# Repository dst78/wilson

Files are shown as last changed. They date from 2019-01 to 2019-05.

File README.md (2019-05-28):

# Wilson :: Sample and Hold

# WARNING: This module is quite buggy in its current state. I advise against using it for now.

This is a relatively straight forward combined noise and sample & hold circuit, with a bunch of adjustment capabilities.

- External sample source and trigger inputs.
- White noise output, S&H output.
- Adjustment knobs for internal sampling rate, S&H range and transposition.

Note that the external trigger input needs *extremely* steep flanking signals. To be honest, I might have overdone this. Consider changing R3 and R4 to higher values if your trigger source doesn't trigger the sampling.

The internal clock is capable of ranges roughly between 0.2Hz and 20Hz.

The sample output can be adjusted in two ways:

- The R13 shift pot transposes the voltage range up and down.
- The R19 range pot increases / decreases the range of voltages.

Note that R13 and R19 are somewhat interdependent.

## Internal trimming abilities

- R12 noise amplification
- R14 noise transposition

Tweak these until the noise out is in the -5V to 5V range.

- R11 S&H amplification

Tweak this until the S&H out is in the -5V to 5V range when the output attenuator R19 is fully open and R13 is centered.

## External Connections

- Input jack for external triggers (normalled to internal clock)
- Input jack for external sampling source (normalled to noise)
- Output jack for noise
- Output jack for S&H signal

- Potentiometer for internal clock rate adjustment
- Potentiometer for S&H transposition (shifts possible voltage range up/down)
- Potentiometer for output attenuation (attenuates voltage range, not volume)

## What's in the name?

The module was named in honor of Nobel price laureates Robert Wilson and Arno Penzias for their discovery of cosmic microwave background radiation.

## Possible improvements

- replace R3/C3 and R4/C4 to allow slightly slower trigger flanks.
- clock LED is hardwired to the internal signals, could move it to flash with external triggers as well.
- change R13 to be less sensitive.

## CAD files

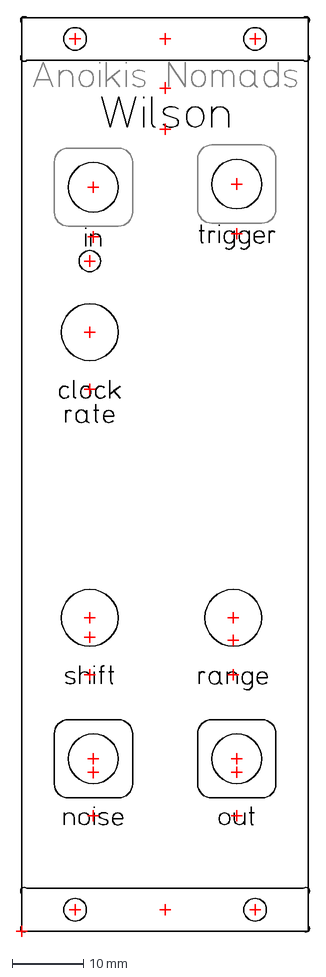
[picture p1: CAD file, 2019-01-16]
eurorack panel/Wilson.dxf
41.3 x 129.4 mm

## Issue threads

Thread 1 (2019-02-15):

trigger input seems to require more than +5V to fire

dst78, 2019-02-15:
The trigger input seems to require more than +5V to fire. At first I thought it would simply need an extremely steep signal flank but that doesn't seem to be the case.

Given the density of the circuit board, investigate the possibilities to internally boost a +5V trigger signal to +10V or whatever is needed through a transistor/opamp.

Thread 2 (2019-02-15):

shift input is too sensitive

dst78, 2019-02-15:
The shift input offsets the S&H noise source between -12V and +12V resulting in very sensitive controls and most of the potentiometer range being wasted since the signal is clamped to +-12V very quickly.

Investigate options on the control board to reduce the potentiometer voltage range.

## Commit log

2019-01-07 initial folder structure commit
    [Wilson.dxf]
2019-01-16 revision A of the circuit diagram
2019-01-16 added panel layout
    [Wilson.dxf]
2019-01-17 added circuit diagram, revision B
2019-02-03 updated Eurorack panel, added silkscreen
